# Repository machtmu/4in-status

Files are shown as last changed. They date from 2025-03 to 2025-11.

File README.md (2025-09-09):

# Status Module Repository

Use Export KiCad Images Workflow

---

<div align="center">
  <div>
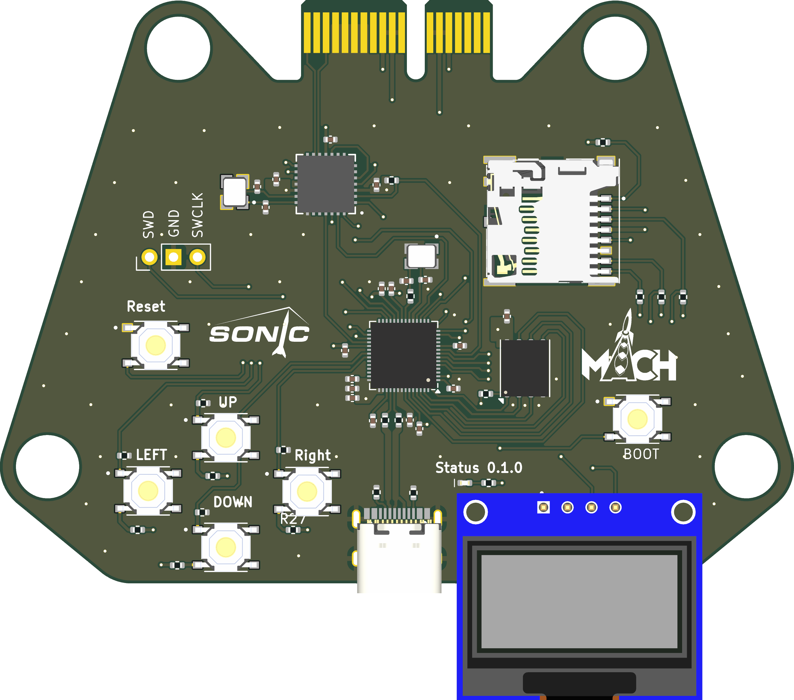
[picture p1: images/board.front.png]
    
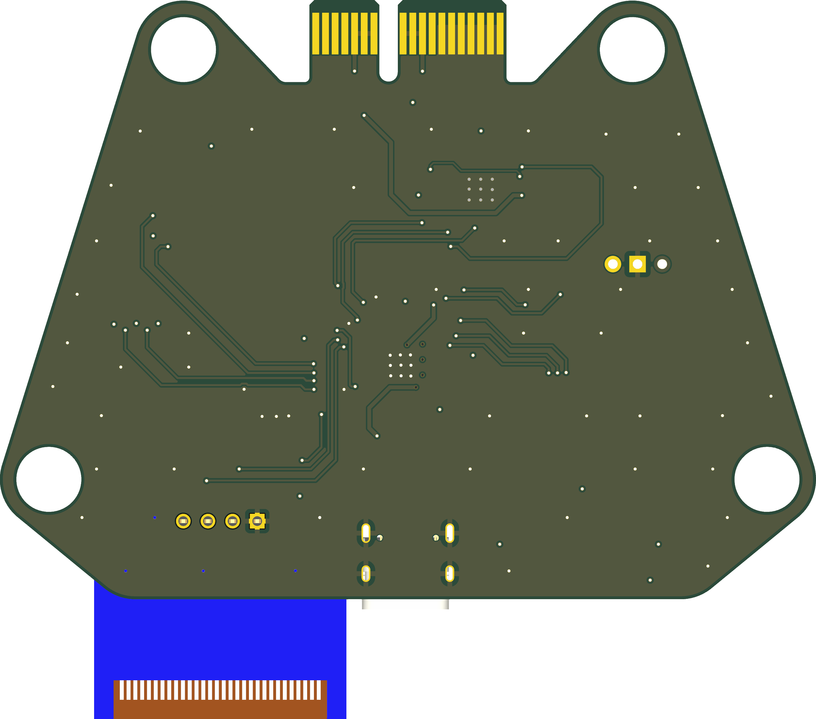
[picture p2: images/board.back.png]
    
    <p><em>3D Render</em></p>
  </div>
  <br>

  <div>
    Schematic<br>
    <p><em>Schematic</em></p>
  </div>
  <br>
  
  <div>
    Front
    Back<br>
    <em>Footprint</em>
  </div>
</div>

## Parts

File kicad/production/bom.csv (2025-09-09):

Designator | Footprint | Quantity | Value | LCSC Part #
C10, C11, C12, C13, C14, C15, C16, C17, C20, C3, C4, C5, C8 | 0402 | 13 | 100 nF | C307331
C18, C23 | 0402 | 2 | 15 pF | C1548
C22, C6 | 0402 | 2 | 22 pF | C70464
C7, C9 | 0402 | 2 | 1 uF | C52923
D1 | 0402 | 1 | LED | C74340
J4 | MOLEX_503398-1892 | 1 | 503398-1892 | C428492
J5 | BUS_PCIexpress_x1 | 1 | Bus_PCI_Express_x1 | n/a
J6 | USB_C_Receptacle_Palconn_UTC16-G | 1 | USB_C_Receptacle_USB2.0_16P | C2765186
R10, R13, R16, R17, R18, R19, R20, R21, R22, R9 | 0402 | 10 | 10K | C60490
R11, R12 | 0402 | 2 | 5.1K | C25905
R14 | 0402 | 1 | 1K | C71623
R24, R25, R26, R3, R6 | 0402 | 5 | 1k | C11702
R4, R5 | 0402 | 2 | 27 | C25100
S10, S11, S12, S7, S8, S9 | SW_TS-1187A-B-A-B | 6 | TS-1187A-B-A-B | C318884
U1 | MODULE_DM-OLED096-636 | 1 | DM-OLED096-636
U2 | QFN-56-1EP_7x7mm_P0.4mm_EP3.2x3.2mm | 1 | RP2040 | C2040
U3 | QFN28_6X6MC_MCH | 1 | MCP25625T-E/ML | C13738
U4 | WSON-8-1EP_6x5mm_P1.27mm_EP3.4x4.3mm | 1 | W25Q128JVP | C190862
X1 | ABM8-272-T3_ABR | 1 | ABM8-272-T3 | C13738
Y1 | OSC_X322516MLB4SI | 1 | X322516MLB4SI | C13738

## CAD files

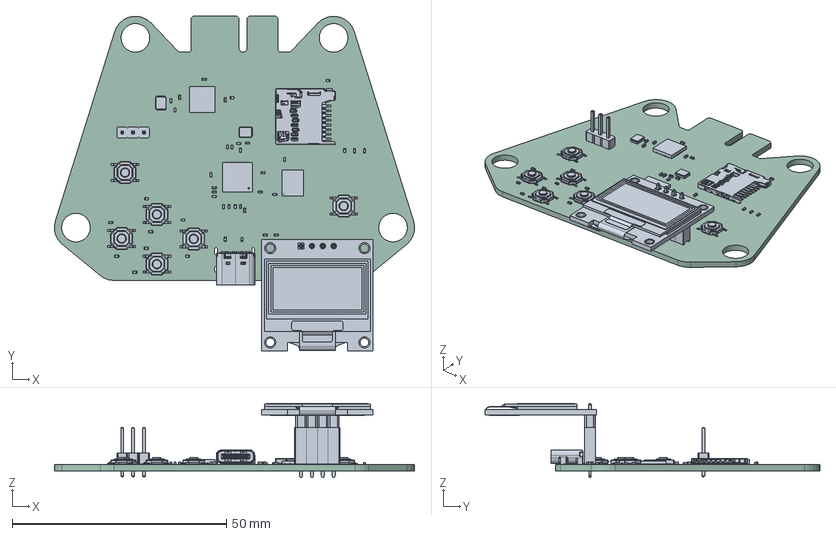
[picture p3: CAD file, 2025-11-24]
images/board.step
84.1 x 78.2 x 17.4 mm
WSON-8-1EP_6x5mm_P1.27mm_EP3.4x4.3mm
R_0402_1005Metric x 20
C_0402_1005Metric x 19
PinHeader_1x03_P2.54mm_Vertical
LED_0402_1005Metric
kicad_embedded_74EC9C574C356922F6A4535285956C6B x 6
USB_C_Receptacle_GCT_USB4105-xx-A_16P_TopMnt_Horizontal
kicad_embedded_5C7316288C16EE99A5C5D029C6DE3FDF x 2
QFN-56-1EP_7x7mm_P0.4mm_EP3.2x3.2mm
DM-OLED096-636_Module
DM-OLED096-636_Panel
PPPC021LFBN-RC_C04
Pin - Gold x 4
kicad_embedded_CA15AE13EDEFA27E5AA1E56830838996
status_PCB

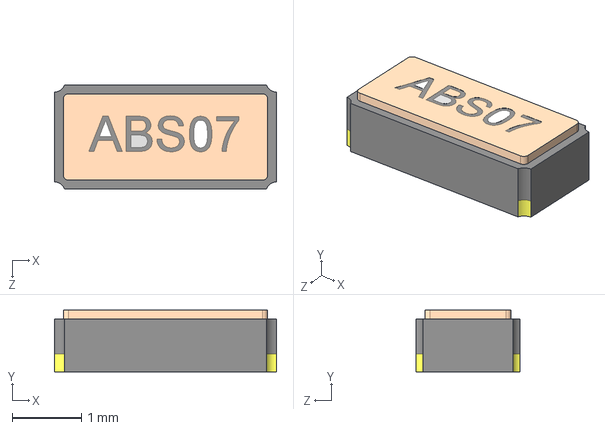
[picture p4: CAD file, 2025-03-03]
kicad/models/ABS07-32.768KHZ-T.step
3.20 x 0.889 x 1.50 mm

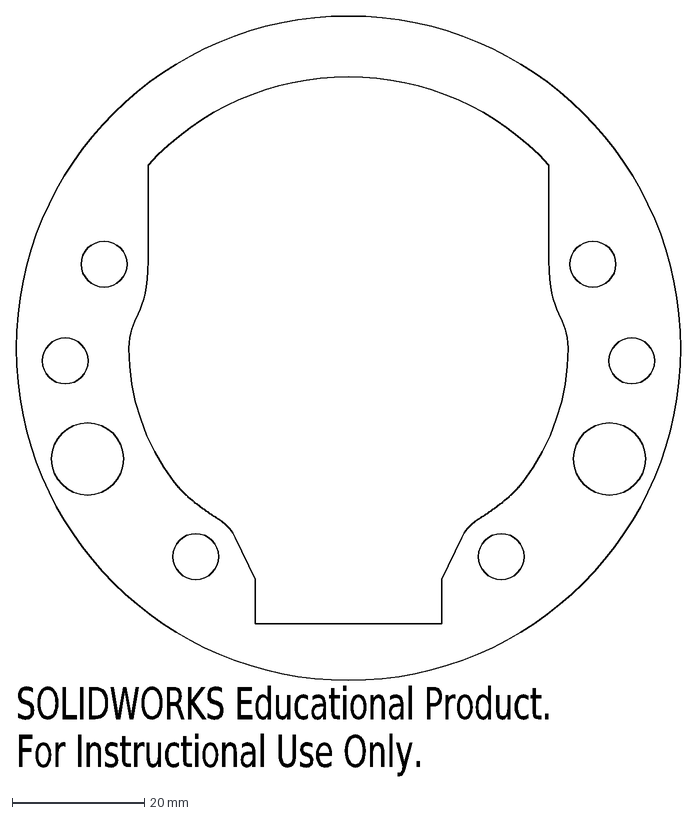
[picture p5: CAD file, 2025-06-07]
kicad/rack.DXF
SOLIDWORKS Educational Product.
For Instructional Use Only.

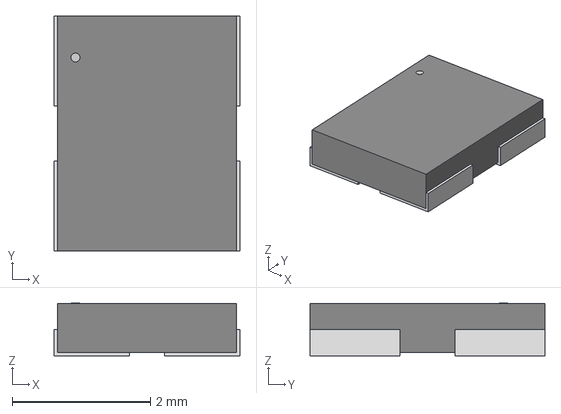
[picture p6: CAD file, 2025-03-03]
kicad/models/ABM8-272-T3_ABR.step
2.69 x 3.40 x 0.765 mm

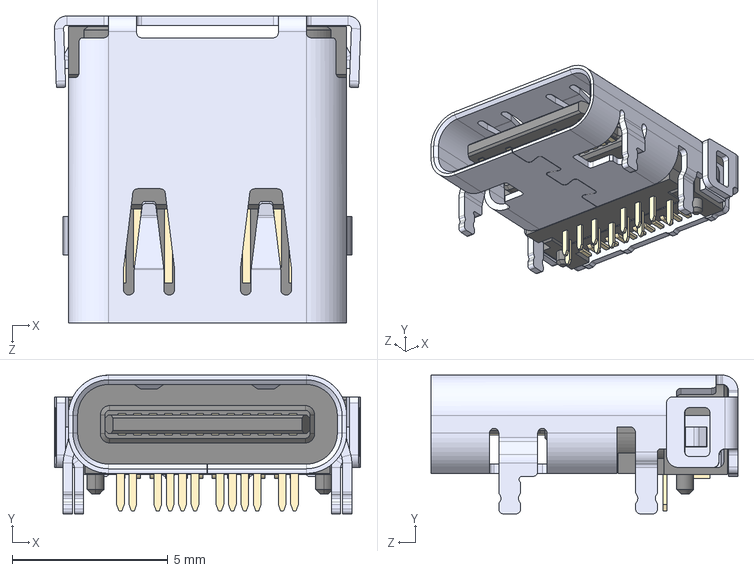
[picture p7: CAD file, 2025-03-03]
kicad/models/TYPE-C-31-M-04.step
9.85 x 4.46 x 9.87 mm

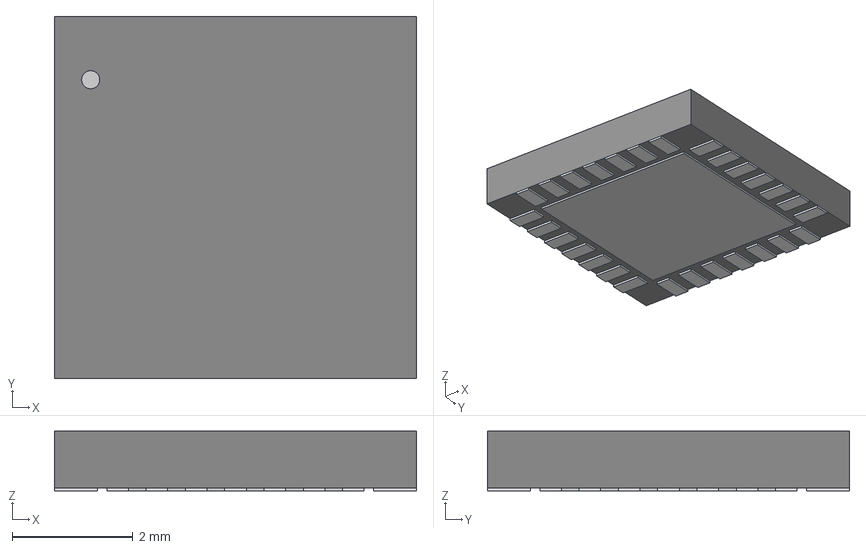
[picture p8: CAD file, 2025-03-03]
kicad/models/QFN28_6X6MC_MCH.step
5.99 x 5.99 x 0.993 mm

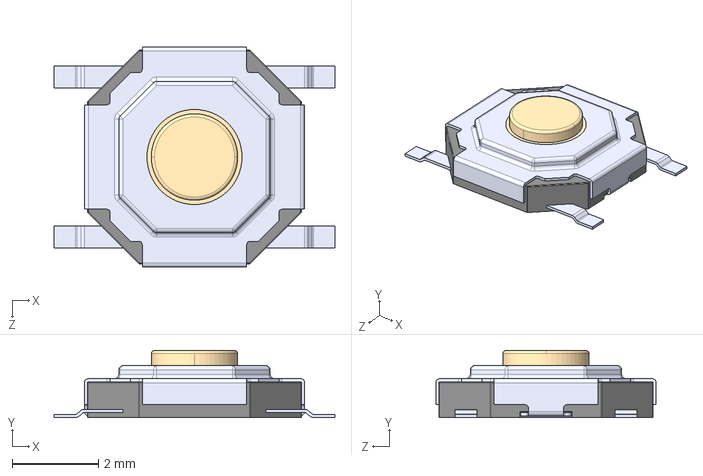
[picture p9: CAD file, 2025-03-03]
kicad/models/TS-1187A-B-A-B.step
6.50 x 1.55 x 5.10 mm

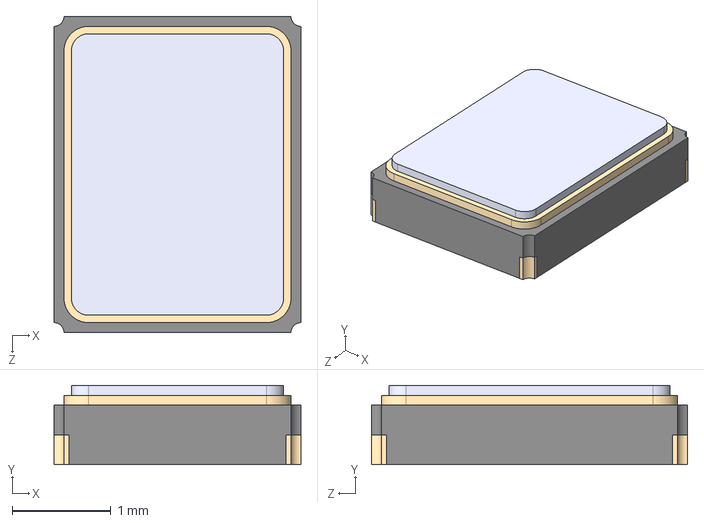
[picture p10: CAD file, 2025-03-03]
kicad/models/X322516MLB4SI.step
2.50 x 0.8 x 3.20 mm

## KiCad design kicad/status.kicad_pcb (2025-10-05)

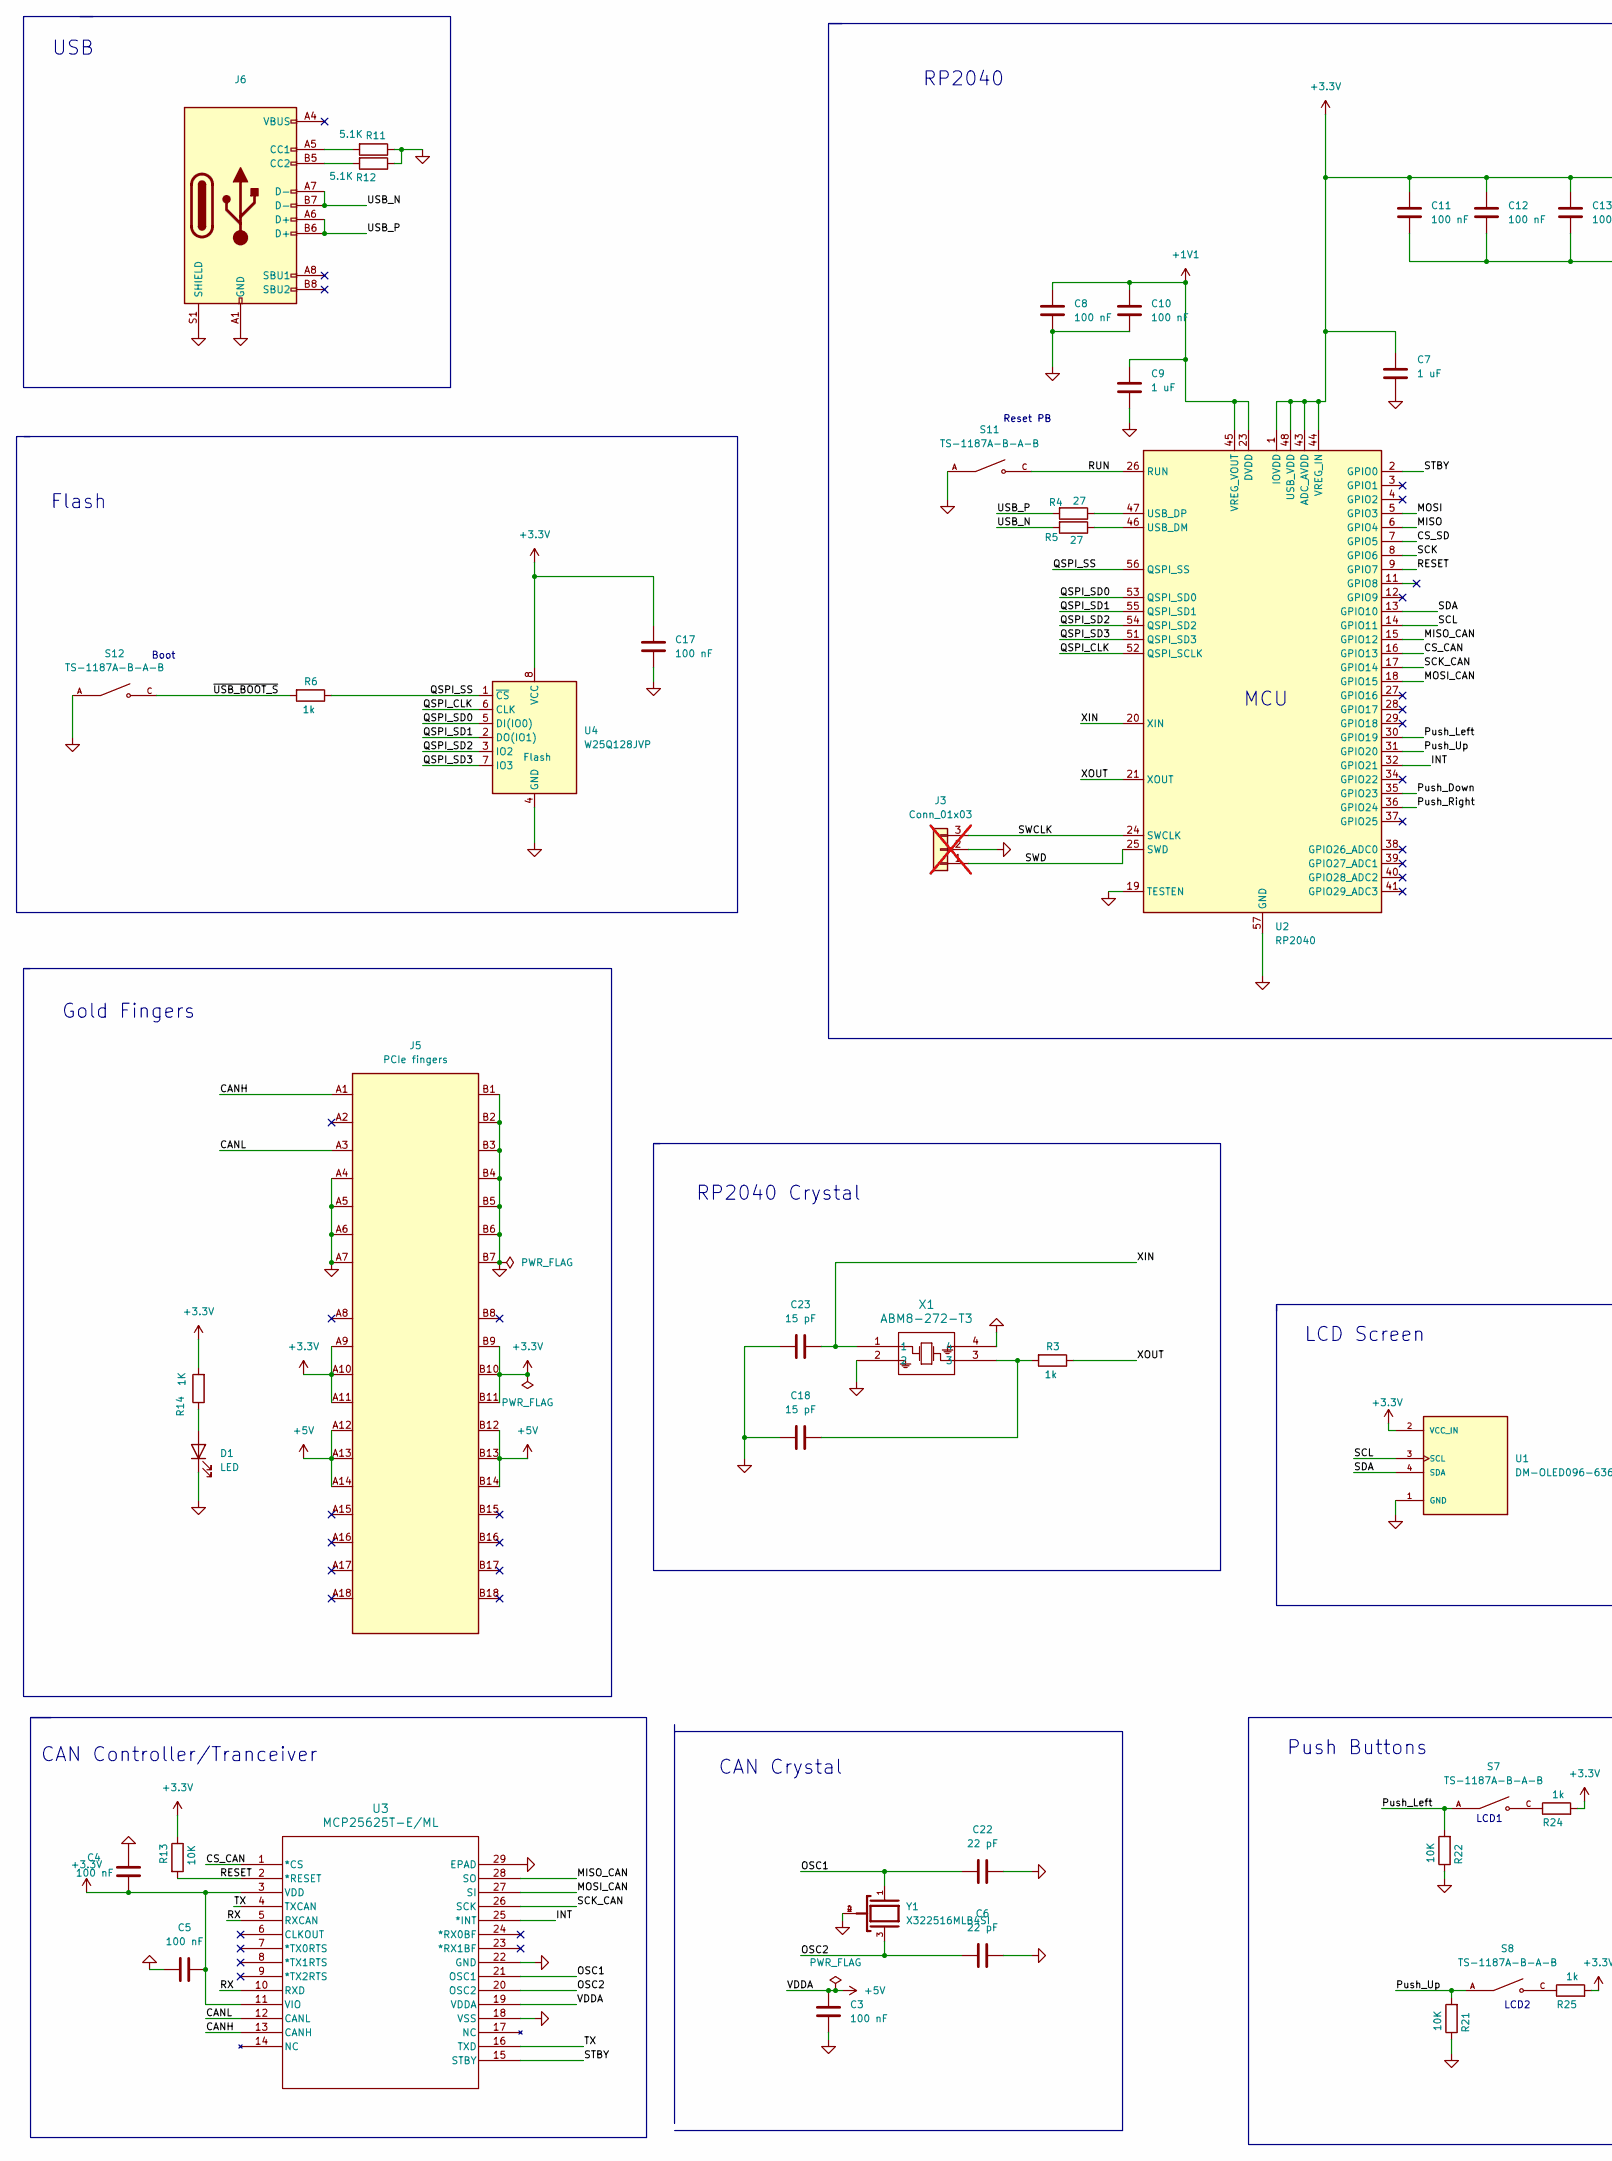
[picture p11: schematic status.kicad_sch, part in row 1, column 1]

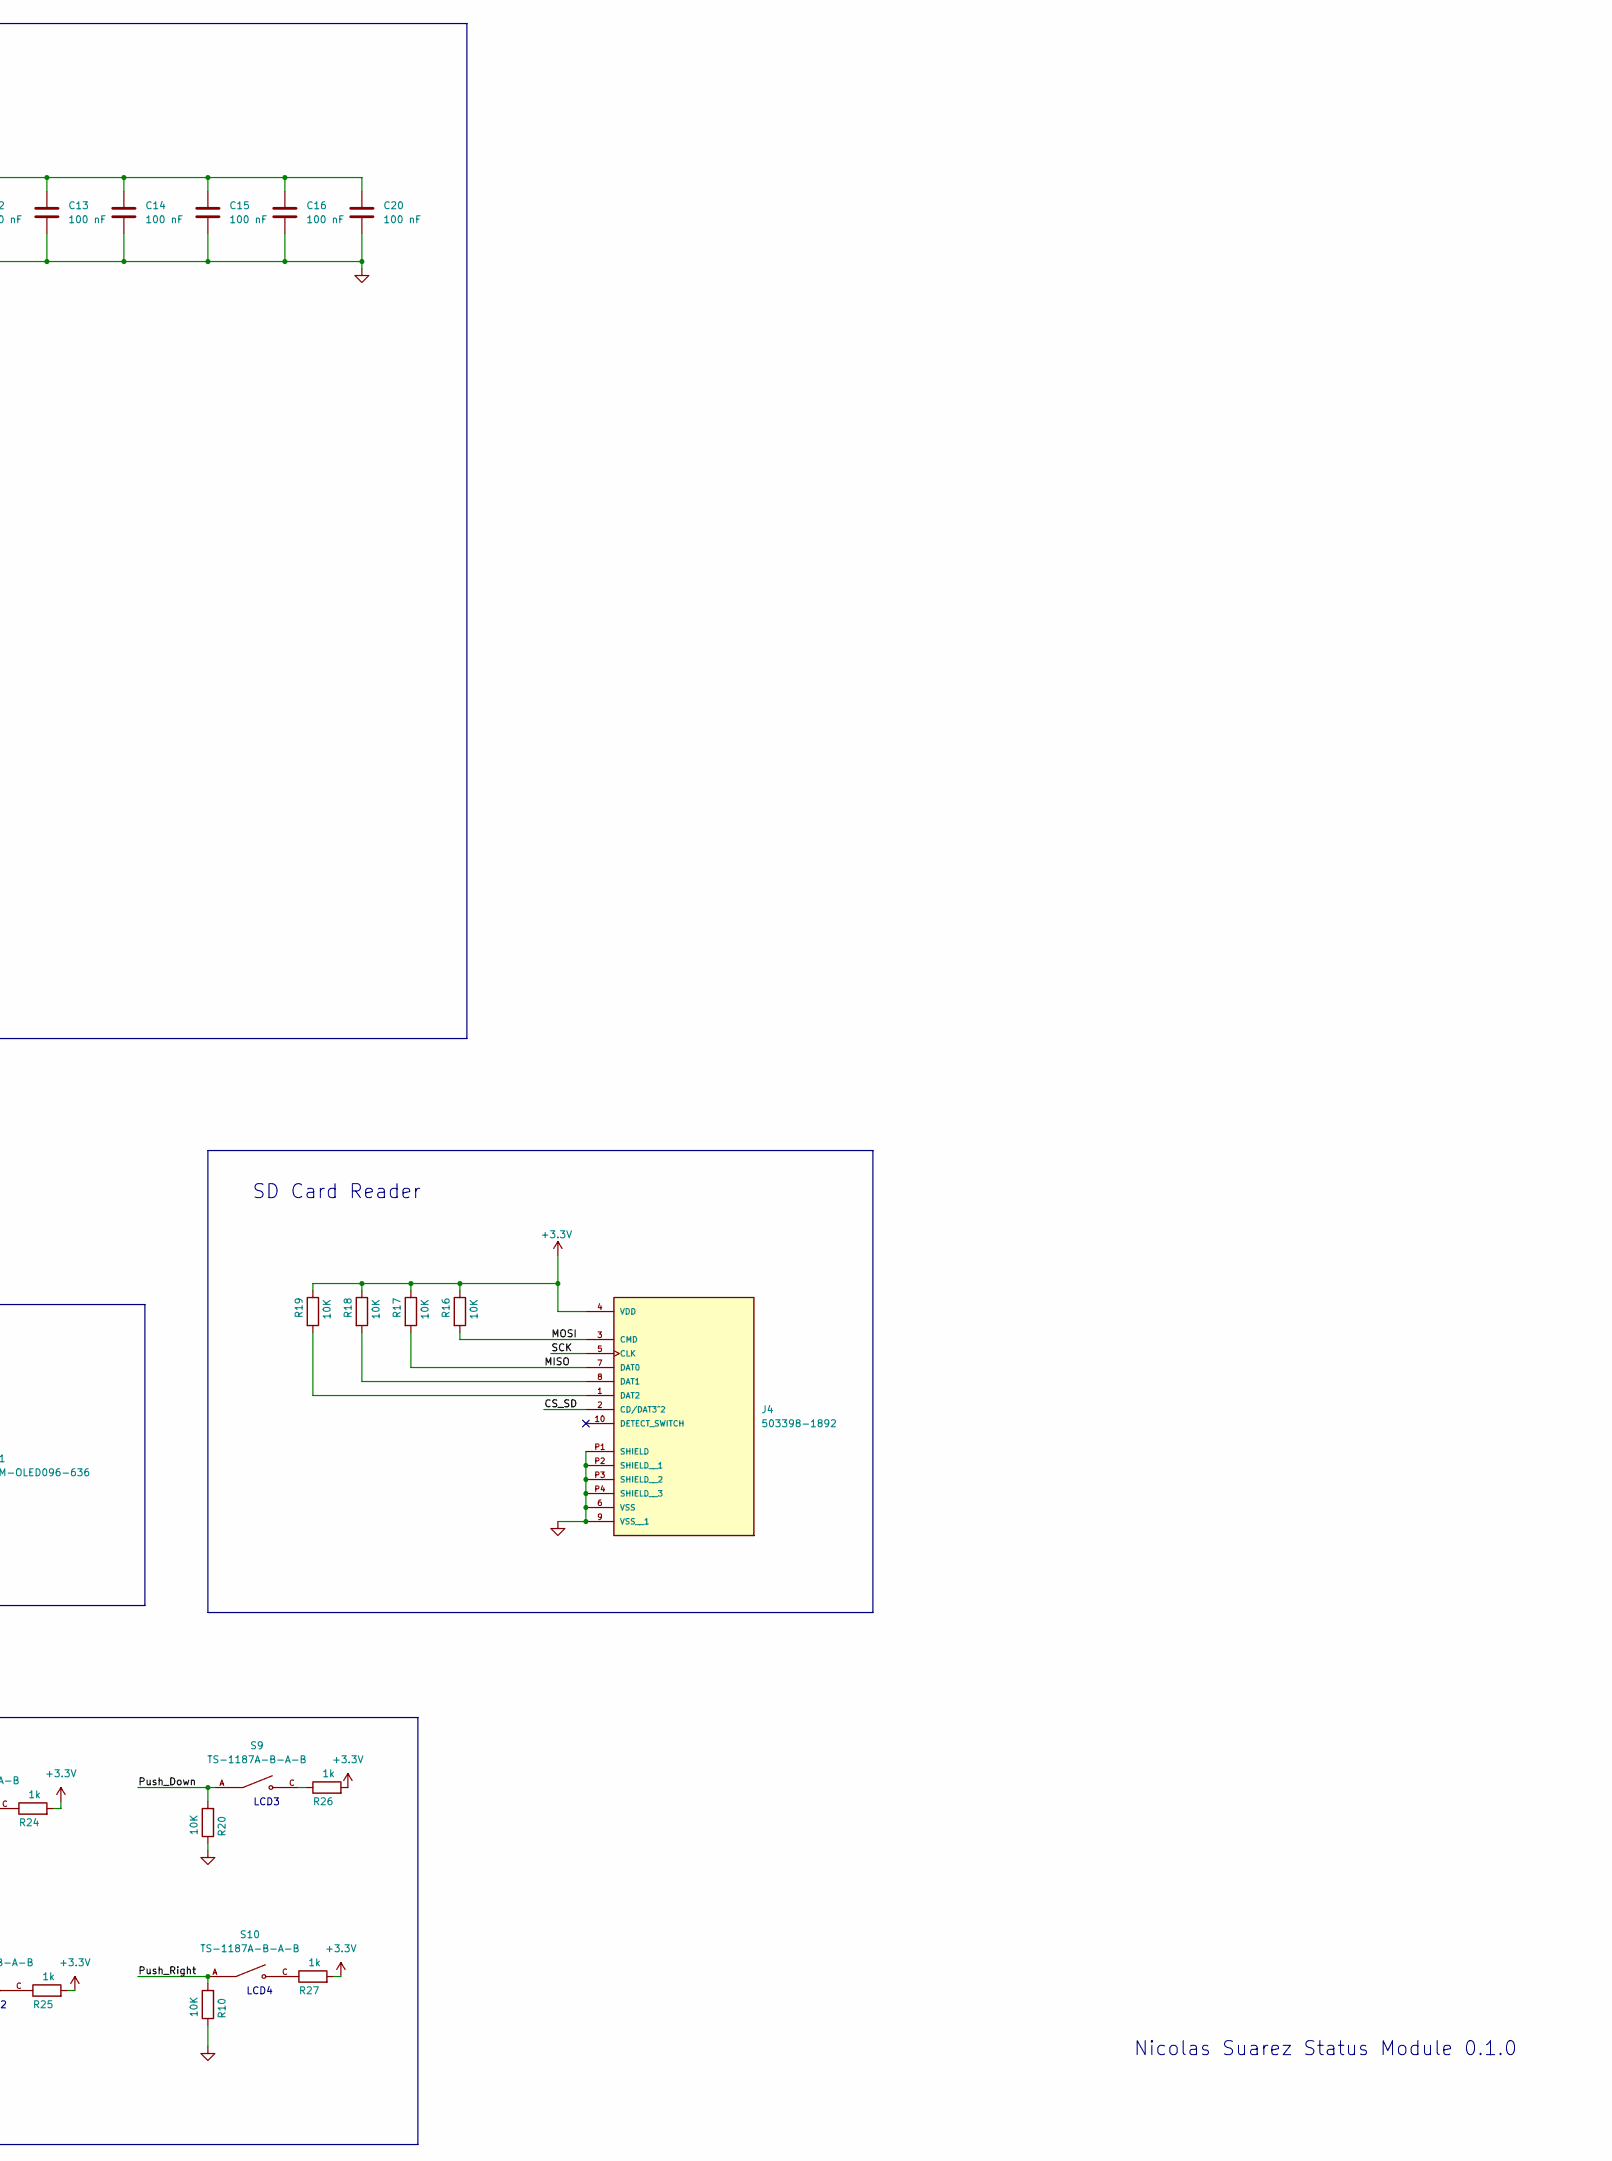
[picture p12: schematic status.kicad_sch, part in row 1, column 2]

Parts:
C3, C4, C5, C8, C10, C11, C12, C13, C14, C15, C16, C17, C20: 100 nF; C_0402_1005Metric; LCSC Part # C307331
C6, C22: 22 pF; C_0402_1005Metric; LCSC Part # C70464
C7, C9: 1 uF; C_0402_1005Metric; LCSC Part # C52923
C18, C23: 15 pF; C_0402_1005Metric; LCSC Part # C1548
D1: LED; LED_0402_1005Metric; LCSC Part # C74340
J3: Conn_01x03; PinHeader_1x03_P2.54mm_Vertical; not fitted
J4: 503398-1892; MOLEX_503398-1892; PARTREV 0; JLCPCB Part # C428492
J5: Bus_PCI_Express_x1; BUS_PCIexpress_x1; LCSC Part # n/a
J6: USB_C_Receptacle_USB2.0_16P; USB_C_Receptacle_Palconn_UTC16-G; LCSC Part # C2765186
R3, R6, R24, R25, R26, R27: 1k; R_0402_1005Metric; LCSC Part # C11702
R4, R5: 27; R_0402_1005Metric; LCSC Part # C25100
R10, R13, R16, R17, R18, R19, R20, R21, R22: 10K; R_0402_1005Metric; LCSC Part # C60490
R11, R12: 5.1K; R_0402_1005Metric; LCSC Part # C25905
R14: 1K; R_0402_1005Metric; LCSC Part # C71623
S7, S8, S9, S10, S11, S12: TS-1187A-B-A-B; SW_TS-1187A-B-A-B; PARTREV A0; LCSC Part # C318884
U1: DM-OLED096-636; MODULE_DM-OLED096-636; PARTREV 2018-09-10
U2: RP2040; QFN-56-1EP_7x7mm_P0.4mm_EP3.2x3.2mm; LCSC C2040
U3: MCP25625T-E/ML; QFN28_6X6MC_MCH; LCSC Part # C191253
U4: W25Q128JVP; WSON-8-1EP_6x5mm_P1.27mm_EP3.4x4.3mm; LCSC C190862
X1: ABM8-272-T3; ABM8-272-T3_ABR; LCSC Part # C20625731
Y1: X322516MLB4SI; OSC_X322516MLB4SI; PARTREV N/A; LCSC Part # C13738

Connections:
+1V1: C8.2, C9.2, C10.2, U2.23 (DVDD), U2.45 (VREG_VOUT), U2.50 (DVDD)
+3.3V: C4.1, C5.1, C7.2, C11.2, C12.2, C13.2, C14.2, C15.2, C16.2, C17.2, C20.2, J4.4 (VDD), J5.A9 (+3.3V), J5.A10 (+3.3V), J5.A11 (~PERST), J5.B9 (JTAG1), J5.B10 (3.3Vaux), J5.B11 (~WAKE), R13.1, R14.2, R16.1, R17.1, R18.1, R19.1, R24.2, R25.2, R26.2, R27.2, U1.2 (VCC_IN), U2.1 (IOVDD), U2.10 (IOVDD), U2.22 (IOVDD), U2.33 (IOVDD), U2.42 (IOVDD), U2.43 (ADC_AVDD), U2.44 (VREG_IN), U2.48 (USB_VDD), U2.49 (IOVDD), U3.3 (VDD), U3.11 (VIO), U4.8 (VCC)
+5V: C3.2, J5.A12 (GND), J5.A13 (REFCLK+), J5.A14 (REFCLK-), J5.B12 (RSVD), J5.B13 (GND), J5.B14 (PETp0), U3.19 (VDDA)
/CANH: J5.A1 (~PRSNT1), U3.13 (CANH)
/CANL: J5.A3 (+12V), U3.12 (CANL)
/CS_CAN: U2.16 (GPIO13), U3.1 (*CS)
/CS_SD: J4.2 (CD/DAT3^2), U2.7 (GPIO5)
/INT: U2.32 (GPIO21), U3.25 (*INT)
/MISO: J4.7 (DAT0), R17.2, U2.6 (GPIO4)
/MISO_CAN: U2.15 (GPIO12), U3.28 (SO)
/MOSI: J4.3 (CMD), R16.2, U2.5 (GPIO3)
/MOSI_CAN: U2.18 (GPIO15), U3.27 (SI)
/OSC1: C22.2, U3.21 (OSC1), Y1.1
/OSC2: C6.2, U3.20 (OSC2), Y1.3
/Push_Down: R20.2, S9.A, U2.35 (GPIO23)
/Push_Left: R22.2, S7.A, U2.30 (GPIO19)
/Push_Right: R10.2, S10.A, U2.36 (GPIO24)
/Push_Up: R21.2, S8.A, U2.31 (GPIO20)
/QSPI_CLK: U2.52 (QSPI_SCLK), U4.6 (CLK)
/QSPI_SD0: U2.53 (QSPI_SD0), U4.5 (DI(IO0))
/QSPI_SD1: U2.55 (QSPI_SD1), U4.2 (DO(IO1))
/QSPI_SD2: U2.54 (QSPI_SD2), U4.3 (IO2)
/QSPI_SD3: U2.51 (QSPI_SD3), U4.7 (IO3)
/QSPI_SS: R6.1, U2.56 (QSPI_SS), U4.1 (~CS)
/RESET: R13.2, U2.9 (GPIO7), U3.2 (*RESET)
/RUN: S11.C, U2.26 (RUN)
/RX: U3.5 (RXCAN), U3.10 (RXD)
/SCK: J4.5 (CLK), U2.8 (GPIO6)
/SCK_CAN: U2.17 (GPIO14), U3.26 (SCK)
/SCL: U1.3 (SCL), U2.14 (GPIO11)
/SDA: U1.4 (SDA), U2.13 (GPIO10)
/STBY: U2.2 (GPIO0), U3.15 (STBY)
/SWCLK: J3.3, U2.24 (SWCLK)
/SWD: J3.1, U2.25 (SWD)
/TX: U3.4 (TXCAN), U3.16 (TXD)
/USB_N: J6.A7 (D-), J6.B7 (D-), R5.2
/USB_P: J6.A6 (D+), J6.B6 (D+), R4.2
/XIN: C23.1, U2.20 (XIN), X1.1
/XOUT: R3.1, U2.21 (XOUT)
/~USB_BOOT_S: R6.2, S12.C
GND: C3.1, C4.2, C5.2, C6.1, C7.1, C8.1, C9.1, C10.1, C11.1, C12.1, C13.1, C14.1, C15.1, C16.1, C17.1, C18.2, C20.1, C22.1, C23.2, D1.1 (K), J3.2, J4.6 (VSS), J4.9 (VSS__1), J4.P1 (SHIELD), J4.P2 (SHIELD__1), J4.P3 (SHIELD__2), J4.P4 (SHIELD__3), J5.A4 (GND), J5.A5 (JTAG2), J5.A6 (JTAG3), J5.A7 (JTAG4), J5.B1 (+12V), J5.B2 (+12V), J5.B3 (+12V), J5.B4 (GND), J5.B5 (SMCLK), J5.B6 (SMDAT), J5.B7 (GND), J6.A1 (GND), J6.A12 (GND), J6.B1 (GND), J6.B12 (GND), J6.S1 (SHIELD), R10.1, R11.1, R12.1, R20.1, R21.1, R22.1, S11.A, S12.A, U1.1 (GND), U2.19 (TESTEN), U2.57 (GND), U3.18 (VSS), U3.22 (GND), U3.29 (EPAD), U4.4 (GND), X1.2, X1.4, Y1.2, Y1.4
unnamed: C18.1, R3.2, X1.3
unnamed: D1.2 (A), R14.1
unnamed: J4.8 (DAT1), R18.2
unnamed: J4.1 (DAT2), R19.2
unnamed: J6.A5 (CC1), R11.2
unnamed: J6.B5 (CC2), R12.2
unnamed: R24.1, S7.C
unnamed: R25.1, S8.C
unnamed: R26.1, S9.C
unnamed: R27.1, S10.C
unnamed: R5.1, U2.46 (USB_DM)
unnamed: R4.1, U2.47 (USB_DP)

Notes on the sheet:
LCD2
SD Card Reader
LCD1
RP2040 Crystal
USB
CAN Crystal
MCU
Boot
Nicolas Suarez Status Module 0.1.0
RP2040
LCD Screen
Gold Fingers
LCD4
Push Buttons
LCD3
Reset PB
CAN Controller/Tranceiver
Flash

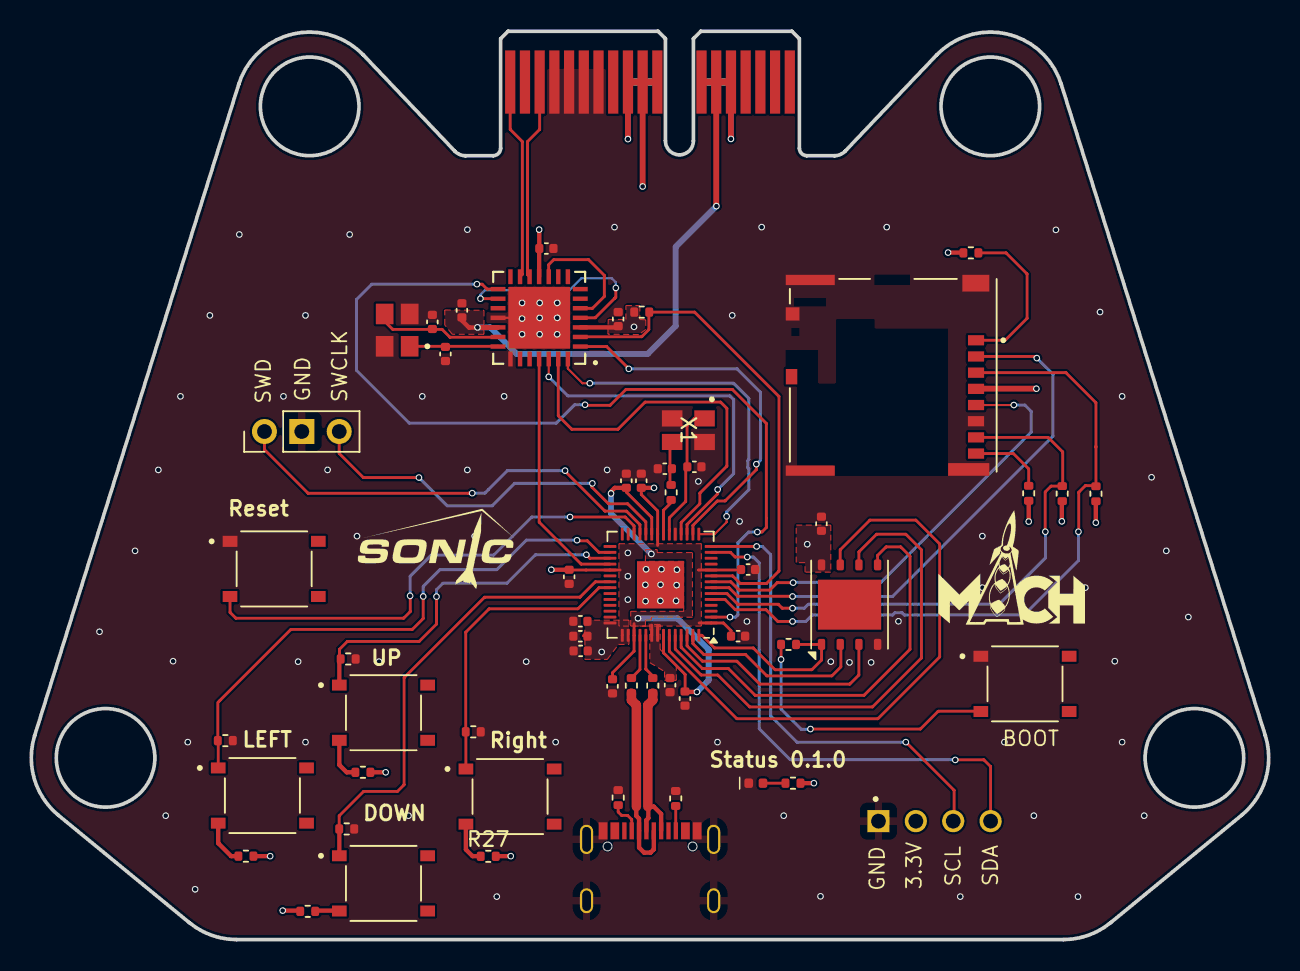
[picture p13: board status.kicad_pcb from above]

Board: 4 copper layers, 84.1 x 61.7 mm, 56 parts (1 on the bottom side), 53 nets.

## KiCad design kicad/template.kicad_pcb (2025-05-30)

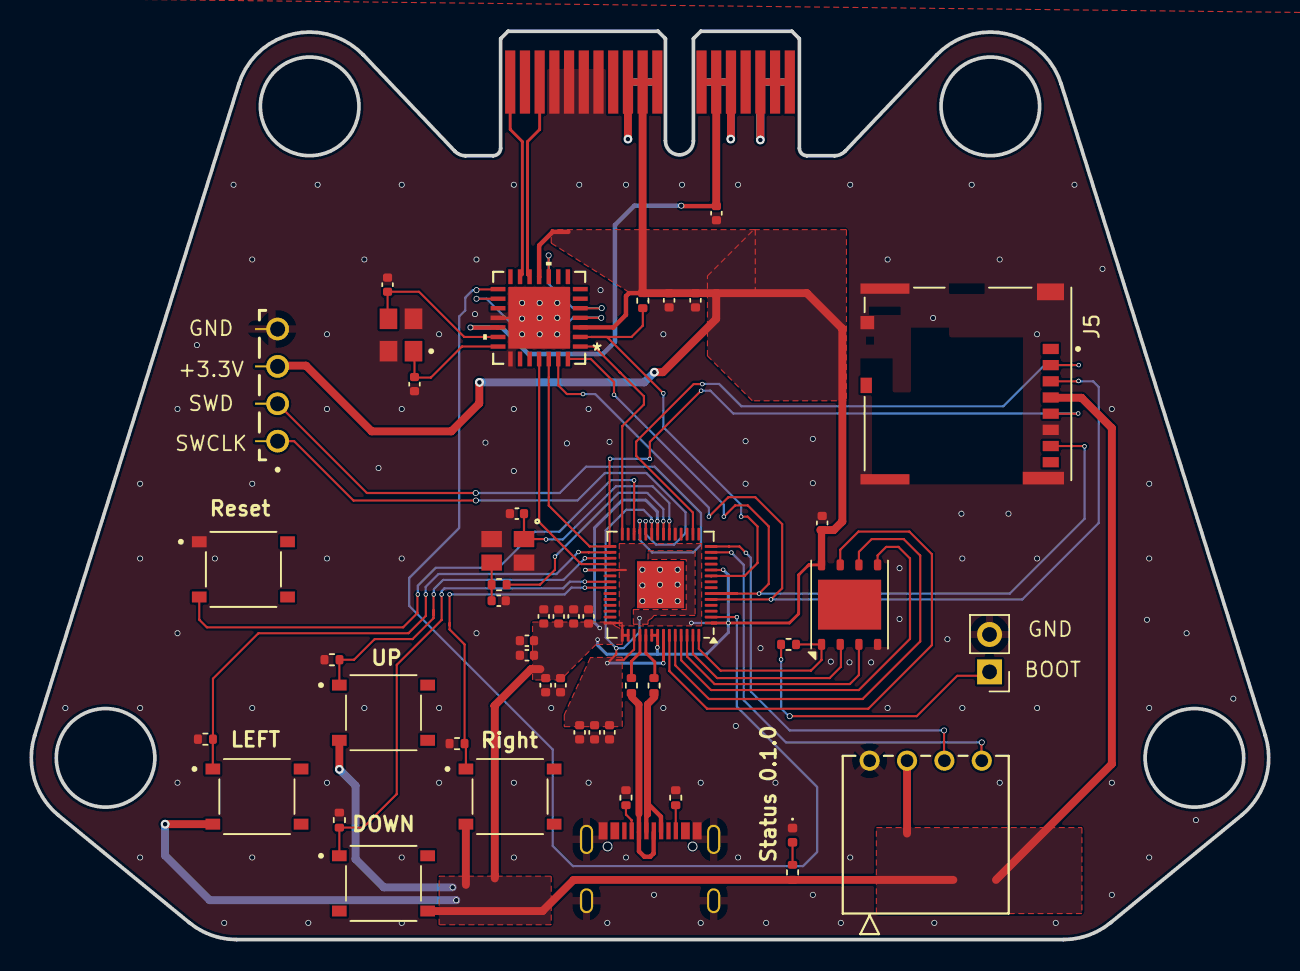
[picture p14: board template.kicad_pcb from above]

Board: 2 copper layers, 84.1 x 61.7 mm, 48 parts (1 on the bottom side), 45 nets.

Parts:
C3, C4, C5, C8, C10, C11, C12, C13, C14, C15, C16, C17, C20: 100 nF; C_0402_1005Metric
C6, C22: 22 pF; C_0402_1005Metric
C7, C9: 1 uF; C_0402_1005Metric
C18, C23: 15 pF; C_0402_1005Metric
D1: LED; LED_0402_1005Metric
J1: Bus_PCI_Express_x1; BUS_PCIexpress_x1
J2: PPTC041LGBN-RC; CONN_PPTC041LGBN-RC_SUL
J3: Conn_01x04; SAMTEC_MTLW-104-X-X-S-X
J5: 503398-1892; MOLEX_503398-1892
J6: USB_C_Receptacle_USB2.0_16P; USB_C_Receptacle_Palconn_UTC16-G
J7: Conn_01x02; PinHeader_1x02_P2.54mm_Vertical
R3, R6: 1k; R_0402_1005Metric
R4, R5: 27; R_0402_1005Metric
R7, R8, R9, R10, R13: 10K; R_0402_1005Metric
R11, R12: 5.1K; R_0402_1005Metric
R14: 1K; R_0402_1005Metric
S7, S8, S9, S10, S11: TS-1187A-B-A-B; SW_TS-1187A-B-A-B
U1: MCP25625T-E/ML; QFN28_6X6MC_MCH
U2: RP2040; QFN-56-1EP_7x7mm_P0.4mm_EP3.2x3.2mm
U4: W25Q128JVP; WSON-8-1EP_6x5mm_P1.27mm_EP3.4x4.3mm
X1: ABM8-272-T3; ABM8-272-T3_ABR
Y1: X322516MLB4SI; OSC_X322516MLB4SI

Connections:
+1V1: C8.2, C9.2, C10.2, U2.23 (DVDD), U2.45 (VREG_VOUT), U2.50 (DVDD)
+3.3V: C4.1, C5.1, C7.2, C11.2, C12.2, C13.2, C14.2, C15.2, C16.2, C17.2, C20.2, J1.A9 (+3.3V), J1.A10 (+3.3V), J1.A11 (~PERST), J1.B9 (JTAG1), J1.B10 (3.3Vaux), J1.B11 (~WAKE), J2.2, J3.3, J5.4 (VDD), R13.1, R14.2, S7.C, S8.C, S9.D, S10.C, U1.3 (VDD), U1.11 (VIO), U2.1 (IOVDD), U2.10 (IOVDD), U2.22 (IOVDD), U2.33 (IOVDD), U2.42 (IOVDD), U2.43 (ADC_AVDD), U2.44 (VREG_IN), U2.48 (USB_VDD), U2.49 (IOVDD), U4.8 (VCC)
+5V: C3.2, J1.A12 (GND), J1.A13 (REFCLK+), J1.A14 (REFCLK-), J1.B12 (RSVD), J1.B13 (GND), J1.B14 (PETp0), U1.19 (VDDA)
+BAT: J1.A16 (PERp0), J1.A17 (PERn0), J1.A18 (GND), J1.B16 (GND), J1.B17 (~PRSNT2), J1.B18 (GND)
/CANH: J1.A1 (~PRSNT1), U1.13 (CANH)
/CANL: J1.A3 (+12V), U1.12 (CANL)
/CS: U1.1 (*CS), U2.28 (GPIO17)
/CS_SD: J5.2 (CD/DAT3^2), U2.16 (GPIO13)
/INT: U1.25 (*INT), U2.32 (GPIO21)
/MISO: J5.7 (DAT0), U1.28 (SO), U2.6 (GPIO4)
/MOSI: J5.3 (CMD), U1.27 (SI), U2.5 (GPIO3)
/OSC1: C22.2, U1.21 (OSC1), Y1.1
/OSC2: C6.2, U1.20 (OSC2), Y1.3
/Push_Down: R8.1, S9.A, U2.35 (GPIO23)
/Push_Left: R7.1, S7.A, U2.30 (GPIO19)
/Push_Right: R9.1, S10.A, U2.36 (GPIO24)
/Push_Up: R10.1, S8.A, U2.31 (GPIO20)
/QSPI_CLK: U2.52 (QSPI_SCLK), U4.6 (CLK)
/QSPI_SD0: U2.53 (QSPI_SD0), U4.5 (DI(IO0))
/QSPI_SD1: U2.55 (QSPI_SD1), U4.2 (DO(IO1))
/QSPI_SD2: U2.54 (QSPI_SD2), U4.3 (IO2)
/QSPI_SD3: U2.51 (QSPI_SD3), U4.7 (IO3)
/QSPI_SS: R6.1, U2.56 (QSPI_SS), U4.1 (~CS)
/RESET: R13.2, U1.2 (*RESET), U2.9 (GPIO7)
/RX: U1.5 (RXCAN), U1.10 (RXD)
/SCK: J5.5 (CLK), U1.26 (SCK), U2.29 (GPIO18)
/SCL: J2.3, U2.14 (GPIO11)
/SDA: J2.4, U2.13 (GPIO10)
/STBY: U1.15 (STBY), U2.2 (GPIO0)
/SWCLK: J3.1, U2.24 (SWCLK)
/SWD: J3.2, U2.25 (SWD)
/TX: U1.4 (TXCAN), U1.16 (TXD)
/USB_N: J6.A7 (D-), J6.B7 (D-), R5.2
/USB_P: J6.A6 (D+), J6.B6 (D+), R4.2
/X_IN: C23.1, U2.20 (XIN), X1.1
/X_OUT: R3.1, U2.21 (XOUT)
/~USB_BOOT_S: J7.1, R6.2
GND: C3.1, C4.2, C5.2, C6.1, C7.1, C8.1, C9.1, C10.1, C11.1, C12.1, C13.1, C14.1, C15.1, C16.1, C17.1, C18.2, C20.1, C22.1, C23.2, D1.1 (K), J1.A4 (GND), J1.A5 (JTAG2), J1.A6 (JTAG3), J1.A7 (JTAG4), J1.B1 (+12V), J1.B2 (+12V), J1.B3 (+12V), J1.B4 (GND), J1.B5 (SMCLK), J1.B6 (SMDAT), J1.B7 (GND), J2.1, J3.4, J5.6 (VSS), J5.9 (VSS__1), J5.P1 (SHIELD), J5.P2 (SHIELD__1), J5.P3 (SHIELD__2), J5.P4 (SHIELD__3), J6.A1 (GND), J6.A12 (GND), J6.B1 (GND), J6.B12 (GND), J6.S1 (SHIELD), J7.2, R7.2, R8.2, R9.2, R10.2, R11.1, R12.1, S11.A, U1.18 (VSS), U1.22 (GND), U1.29 (EPAD), U2.19 (TESTEN), U2.57 (GND), U4.4 (GND), X1.2, X1.4, Y1.2, Y1.4
unnamed: C18.1, R3.2, X1.3
unnamed: D1.2 (A), R14.1
unnamed: J6.A5 (CC1), R11.2
unnamed: J6.B5 (CC2), R12.2
unnamed: S11.C, U2.26 (RUN)
unnamed: R5.1, U2.46 (USB_DM)
unnamed: R4.1, U2.47 (USB_DP)

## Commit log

2025-03-03 Update images
    [board.step]
2025-03-03 init status module
    [template.kicad_pcb, template.kicad_sch]
2025-03-14 Update schematic
    [template.kicad_pcb, template.kicad_sch]
2025-03-20 update schematic and pcb layout
    [template.kicad_pcb, template.kicad_sch]
2025-03-24 update BOM
    [template.kicad_pcb, template.kicad_sch]
2025-05-16 Changed Schematic
    [template.kicad_pcb, template.kicad_sch]
2025-05-22 Update PCB Layout
    [template.kicad_pcb, template.kicad_sch]
2025-05-23 PCB Layout update
    [template.kicad_pcb, template.kicad_sch]
2025-05-31 Update PCB Layout and Change file Names to Status
    [status.kicad_pcb, status.kicad_sch]
2025-06-07 Updated PCB Layout
    [status-B_Cu.gbr, status-B_Mask.gbr, status-B_Paste.gbr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]
2025-06-07 update rack dxf outline
    [rack.DXF, status.kicad_pcb]
2025-06-14 PCB Update
    [status.kicad_pcb]
2025-07-22 Pcb layout updated
    [bom.csv, designators.csv, positions.csv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]
2025-08-04 SD Card Update
    [status.kicad_pcb, status.kicad_sch]
2025-08-05 General Updates
    Moved CAN transmitter to separate SPI line.
    Updated rp2040 clock.
    Fixed debug pins.
    Updated nets.
    [status.kicad_pcb, status.kicad_sch]
2025-08-05 General update schematic and PCB
    [status.kicad_pcb, status.kicad_sch]
2025-08-27 Fxed 3d Body PB
    [status.kicad_pcb]
2025-08-27 updated schematic
    [status.kicad_sch]
2025-08-27 added silkscreen to LCD screen pins
    [status.kicad_pcb]
2025-08-27 Updated silkscreen
    [status.kicad_pcb]
2025-09-06 Changes on the PCB layout
    [bom.csv, designators.csv, positions.csv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]
2025-09-09 Organized schematic into functional blocks
    [status.kicad_sch]
2025-09-14 PCB layout changes
    [status.kicad_pcb, status.kicad_sch]
2025-10-05 Added JLCPCB Design Rules and Fixed DRCs
    [status.kicad_pcb]
2025-10-05 Fixed DRCs
    [status.kicad_pcb]
